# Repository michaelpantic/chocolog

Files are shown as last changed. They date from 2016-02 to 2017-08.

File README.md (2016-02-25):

# chocolog

Folder description:
--------------------

- src: All arduino source files
- libraries: All external libraries to be copied in users library folder
- libraries_root: Libraries that need to be exchanged in /usr/share/arduino/libraries. Just the LCD Library that supports shift registers out of the box.

Used Hardware:
--------------

- Arduno Uno
- Sparkfun micro SD-Shield
- Basic 16x2 Character LCD 5V and Shift Register 74HC595 (connected using SPI)
- DS1307RTC Clock break out (connected using I2C)
- 10x DS18B20 Temperature Sensor (Connected using single pin)

Bill of material:
-----------------
- Real Time Clock Module x1
- Audio Cable TRRS - 18" (pigtail) x3
- Shift Register 8-Bit - 74HC595 x2
- Trimpot 10K with Knob x1
- Resistor Kit - 1/4W (500 total) x1
- Audio Jack - 3.5mm (Panel Mount) x3
- Metal Pushbutton - Momentary (16mm, Red) x1
- Metal Pushbutton - Momentary (16mm, Blue) x1
- microSD Shield x1
- Arduino Uno - R3 x1
- Basic 16x2 Character LCD - White on Black 5V x1
- Hook-up Wire - Black (22 AWG) x1
- Heat Shrink - Black 5' x 1/4" x1
- Arduino Stackable Header - 8 Pin x3
- Arduino Stackable Header - 6 Pin x2
- Screw - Phillips Head (1/2", 4-40, 10 pack) x1
- Nut - Metal (4-40, 10 pack) x1
- DC Barrel Jack - Panel Mount x1
- Standoff - Nylon (4-40; 3/8"; 10 pack) x1
- Enclosure - Aluminum (120x95x35mm) x1
- Temperature Sensor - Waterproof (DS18B20) x10
- Wall Adapter Power Supply - 5V DC 2A (Barrel Jack) x1

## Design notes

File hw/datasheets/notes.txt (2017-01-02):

bq24072 - see ti reference design
 - max Vout 3.7v / min Vout >3.4v
 - Use low dropout regulator for 3.3.v (that also supports up to 5v)
 - Use boost converter for 5V

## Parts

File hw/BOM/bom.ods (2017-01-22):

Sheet: Sheet1
BOM Logger
Supplier | Count | Subsystem | Order N | Description | Currency | Item Cost | Total per Device
Sparkfun
 | 1 | UI | LCD-00709 | Basic 16x2 Character LCD - White on Black 5V | USD | 15.95 | 15.95
 | 1 | UI | PRT-13838 | Enclosure - Aluminum (120x94.5x34mm) | USD | 4.95 | 4.95
 | 10 | SENS | SEN-11050 | Temperature Sensor - Waterproof (DS18B20) | USD | 9.95 | 99.5
 | 1 | PCB | PRT-0078 | Coin cell Holder | USD | 1.5 | 1.5
 | 4 | PWR/SIG | PRT-11475 | Panel Connectors | USD | 2.95 | 11.8
 | 1 | PWR | TOL-12889 | Wall Adapter Power Supply - 5V DC 2A (Barrel Jack) | USD | 5.95 | 5.95
 | 1 | UI | PRT-10877 | 2X3 Shrouded Male Header | USD | 1.5 | 1.5
 | 1 | UI | PRT-10651 | 2X3 Crimp on Female Header | USD | 0.35 | 0.35
 | 1 | UI | PRT-08506 | 2X5 Shrouded Male Header | USD | 1.5 | 1.5
 | 1 | UI | PRT-10650 | 2x5 Crimp on Female Header | USD | 0.5 | 0.5
 | 1 | PCB | COM-09806 | Trimpot | USD | 0.95 | 0.95
 |  |  |  | Breakaway headesr
 |  |  |  | 32.768 khz oscilator | USD | 0.48 | 0
 |  |  |  | FTDI Cable
 | 1 | MC | COM-08720 | Mini Pushbutton Switch – SMD | USD | 0.5 | 0.5
 | 1 | Common | CAB-10647 | Ribbon Cable | USD | 4.95
 | 1 | MC | COM-00536 | Crystal 16 MHZ |  | 0.95
Adafruit
 | 1 | PWR | 1781 | Lithium Ion Cylindrical Battery - 3.7v 2200mAh | USD | 9.95 | 9.95
 | 1 | PWR | 1944 | PowerBoost 500 Charger - Rechargeable 5V Lipo USB Boost @ 500mA+ | USD | 14.95 | 14.95
 | 1 | UI | COM-11967 | Metal Pushbutton - Momentary (16mm, Blue) | USD | 4.95 | 4.95
 | 1 | UI | COM-11966 | Metal Pushbutton - Momentary (16mm, Red) | USD | 4.95 | 4.95
 | 1 | UI | COM-11974 | Metal Pushbutton - Latching (16mm, Yellow) | USD | 4.95 | 4.95
Elecrow
 | 1 | PCB |  | PCB | USD | 10 | 10
Digikey
 | 1 | PCB | 478-4061-1-ND | SD SLOT | USD | 5.4 | 5.4
 | 1 | PCB | ATMEGA328-PU-ND | MC | USD | 3.24 | 3.24
 | 1 | PCB | ED3050-5-ND | DIP28 socket | USD | 0.32 | 0.32
 | 1 | RTC | DS1307Z+-ND | RTC Clock | USD | 3.13 | 3.13
 | 1 | PCB | 296-14529-1-ND | Hex converter | USD | 0.43 | 0.43
 | 1 | PCB | 568-1483-1-ND | Shift register 74LS595D | USD | 0.45 | 0.45
 | 3 | RTC | 399-3677-1-ND | 0.1uf Capacitor | USD | 0.36 | 1.08
 | 3 | RTC | 311-4.70KFRCT-ND | 1206 4.7kOhm | USD | 0.09 | 0.27
 | 1 | PWR | MCP1700T3302ETTCT-ND | LDO regulator | USD | 0.38 | 0.38
 | 4 | PWR | 399-9449-1-ND | 1uf 1206 Capacitor | USD | 0.33 | 1.32
 | 2 | MC | 311-10.0KFRCT-ND | 1206 10kOhm
 | 2 | MC | 399-8165-1-ND | 22pf 1206 Capacitor |  |  | 210.72
 | 1 | UI | 311-8.2ERCT-ND | 1206 6 Ohm

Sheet: Sheet2
Capacity | 2200 | [mAh]
Votlage | 3.7 | [V]
 | 8.14 | [Wh]
Nominal V | 5 | [V]
Average Cur | 25 | [mA]
Efficiency | 0.85
 | 0.10625 | [W/h]
 | 76.6117647059
Orders
Supplier | What | Amount | Curr | Shipped | Received | Billed | Tracking
Elecrow | PCB 10x | 76.61 | USD | X | X
DX | 25x GX16 connector | 42.59 | USD | X |  |  | RC316704439NL
Adafruit | Buttons, Lipo charger, batteries | 168 | USD | X | X
Sparkfun | Loads of stuff | 547 | USD | X | X
Digikey | Loads of other stuff | 67 | EUR | X | X
Sorotec | Fraeser | 28 | EUR | X | X
Adafruit v2 | 5xHumid / 2 metal red/ 2 metal blue/3 onoff white / 3 bat / 3 charger | 228
Sparkfun v2 | 22 x ds18b20, 2 x case, 1x Display, +35 Random | 348.66
Digikey v2 |  | 73
 | Total orderings: | 1578.86
 | Flight | 940
 |  | 2518.86
 |  | 503.772
 |  | 2375
DX-16
 | Gehäuse + Sensoren | 3
 | Durchschleif strom | 1
 | Durchschleif sensor | 1

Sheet: Sheet3
Ordering v2
Digikey
 |  | HM1458-ND | Case | 6
 | PCB | 478-4061-1-ND | SD SLOT | 3
 | PCB | ATMEGA328-PU-ND | MC | 2
 | PCB | ED3050-5-ND | DIP28 socket | 2
 | RTC | DS1307Z+-ND | RTC Clock | 3
 | PCB | 296-14529-1-ND | Hex converter | 3
 | PCB | 568-1483-1-ND | Shift register 74LS595D | 3
 | RTC | 399-3677-1-ND | 0.1uf Capacitor | 10
 | RTC | 311-4.70KFRCT-ND | 1206 4.7kOhm
 | PWR | MCP1700T3302ETTCT-ND | LDO regulator | 3
 | PWR | 399-9449-1-ND | 1uf 1206 Capacitor | 10
 | MC | 311-10.0KFRCT-ND | 1206 10kOhm | 5
 | MC | 399-8165-1-ND | 22pf 1206 Capacitor | 10
 | UI | 311-8.2ERCT-ND | 1206 6 Ohm | 5
 |  | T1348-1-ND | Cable | 5
Adafruit
 | PWR | 1781 | Lithium Ion Cylindrical Battery - 3.7v 2200mAh | 3
 | PWR | 1944 | PowerBoost 500 Charger - Rechargeable 5V Lipo USB Boost @ 500mA+ | 3
 | UI | COM-11967 | Metal Pushbutton - Momentary (16mm, Blue) | 2
 | UI | COM-11966 | Metal Pushbutton - Momentary (16mm, Red) | 2
 | UI | COM-11974 | Metal Pushbutton - Latching (16mm, Yellow) | 3
 |  |  | SHT31 | 5
Sparkfun
 | UI | LCD-00709 | Basic 16x2 Character LCD - White on Black 5V | 2
 | UI | PRT-13838 | Enclosure - Aluminum (120x94.5x34mm) | 2
 | SENS | SEN-11050 | Temperature Sensor - Waterproof (DS18B20) | 22
 | PCB | PRT-0078 | Coin cell Holder | 3
 | PWR | TOL-12889 | Wall Adapter Power Supply - 5V DC 2A (Barrel Jack) | 3
 | UI | PRT-10877 | 2X3 Shrouded Male Header | 2
 | UI | PRT-10651 | 2X3 Crimp on Female Header | 2
 | UI | PRT-08506 | 2X5 Shrouded Male Header | 2
 | UI | PRT-10650 | 2x5 Crimp on Female Header | 2
 | PCB | COM-09806 | Trimpot | 2
 |  |  | Breakaway headesr | X
 |  |  | 32.768 khz oscilator | 3
 |  |  | FTDI Cable | 1
 | MC | COM-08720 | Mini Pushbutton Switch – SMD | 3
 | MC | COM-00536 | Crystal 16 MHZ | 3
 |  |  | Stecker | 5

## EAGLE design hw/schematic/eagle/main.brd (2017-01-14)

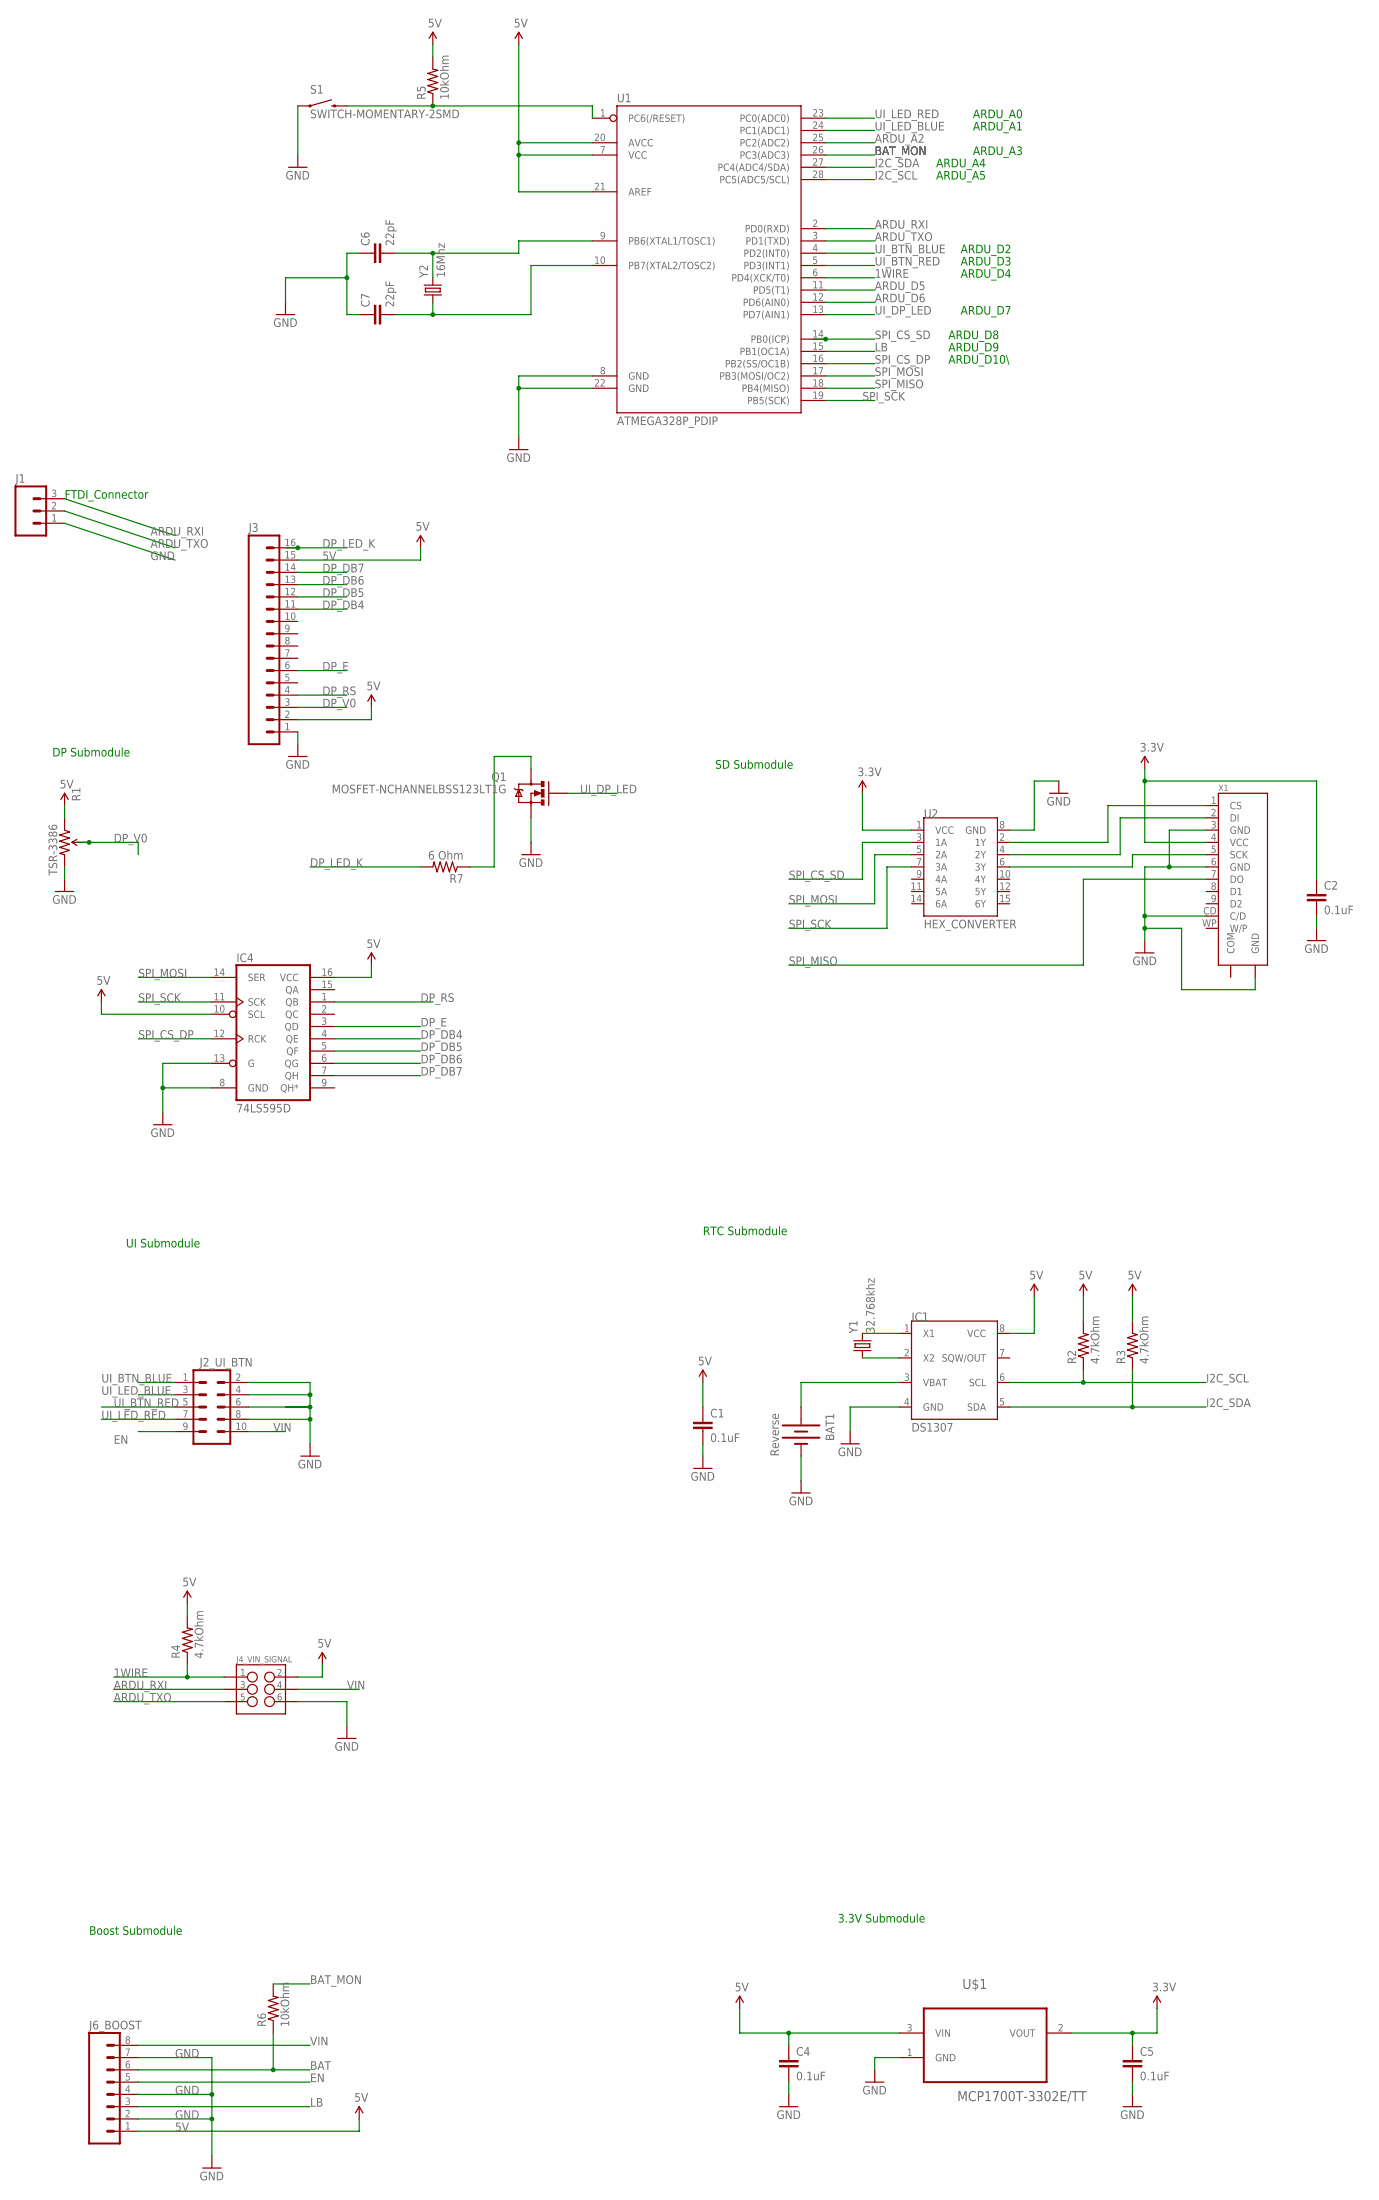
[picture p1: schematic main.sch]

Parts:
BAT1: Reverse; BATTCOM_20MM_PTH
C1, C2, C4, C5: 0.1uF; 1206
C6, C7: 22pF; 1206
IC1: DS1307; SOIC-8
IC4: 74LS595D; SO16
J1: M03LOCK; 1X03_LOCK
J2_UI_BTN: M05X2SHD; 2X5-SHROUDED
J3: M16PTH; 1X16
J4_VIN_SIGNAL: M03X2SHROUD; 2X3-SHROUDED
J6_BOOST: M08; 1X08_ROUND
Q1: MOSFET-NCHANNELBSS123LT1G; SOT23-3
R1: TSR-3386; 3386U
R2, R3, R4: 4.7kOhm; 1206
R5, R6: 10kOhm; 1206
R7: 6 Ohm; 1206
S1: SWITCH-MOMENTARY-2SMD; TACTILE-SWITCH-SMD
U1: ATMEGA328P_PDIP; DIL28-3
U2: HEX_CONVERTER; SO016
U$1: MCP1700T-3302E/TT; SOT95P237X112-3N
X1: SD-SOCKET-AVX
Y1: 32.768khz; CRYSTAL-32KHZ-SMD-MELF
Y2: 16Mhz; HC49US

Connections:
1WIRE: J4_VIN_SIGNAL.1, R4.1, U1.6 (PD4(XCK/T0))
3.3V: C2.1, C5.1, U2.1 (VCC), U$1.2 (VOUT), X1.4 (VCC)
5V: C1.1, C4.1, IC1.8 (VCC), IC4.10 (SCL), IC4.16 (VCC), J3.2, J3.15, J4_VIN_SIGNAL.2, J6_BOOST.1, R1.1 (CCW), R2.2, R3.2, R4.2, R5.2, U1.7 (VCC), U1.20 (AVCC), U1.21 (AREF), U$1.3 (VIN)
ARDU_A2: U1.25 (PC2(ADC2))
ARDU_D5: U1.11 (PD5(T1))
ARDU_D6: U1.12 (PD6(AIN0))
ARDU_RXI: J1.3, J4_VIN_SIGNAL.3, U1.2 (PD0(RXD))
ARDU_TXO: J1.2, J4_VIN_SIGNAL.5, U1.3 (PD1(TXD))
BAT: J6_BOOST.6, R6.1
BAT_MON: R6.2, U1.26 (PC3(ADC3))
DP_DB4: IC4.4 (QE), J3.11
DP_DB5: IC4.5 (QF), J3.12
DP_DB6: IC4.6 (QG), J3.13
DP_DB7: IC4.7 (QH), J3.14
DP_E: IC4.3 (QD), J3.6
DP_LED_K: J3.16, R7.2
DP_RS: IC4.1 (QB), J3.4
DP_V0: J3.3, R1.2 (WIPER)
EN: J2_UI_BTN.9, J6_BOOST.5
GND: BAT1.2 (-), C1.2, C2.2, C4.2, C5.2, C6.1, C7.1, IC1.4 (GND), IC4.8 (GND), IC4.13 (G), J1.1, J2_UI_BTN.2, J2_UI_BTN.4, J2_UI_BTN.6, J2_UI_BTN.8, J3.1, J4_VIN_SIGNAL.6, J6_BOOST.2, J6_BOOST.4, J6_BOOST.7, Q1.2 (S), R1.3 (CW), S1.1, U1.8 (GND), U1.22 (GND), U2.8 (GND), U$1.1 (GND), X1.3 (GND), X1.6 (GND), X1.CD (C/D), X1.GND@2 (GND)
I2C_SCL: IC1.6 (SCL), R2.1, U1.28 (PC5(ADC5/SCL))
I2C_SDA: IC1.5 (SDA), R3.1, U1.27 (PC4(ADC4/SDA))
LB: J6_BOOST.3, U1.15 (PB1(OC1A))
unnamed: BAT1.1 (+), IC1.3 (VBAT)
unnamed: IC1.2 (X2), Y1.X1 (1)
unnamed: IC1.1 (X1), Y1.X2 (2)
unnamed: U2.2 (1Y), X1.1 (CS)
unnamed: U2.4 (2Y), X1.2 (DI)
unnamed: U2.6 (3Y), X1.5 (SCK)
unnamed: R5.1, S1.3 (2), U1.1 (PC6(/RESET))
unnamed: Q1.3 (D), R7.1
unnamed: C6.2, U1.9 (PB6(XTAL1/TOSC1)), Y2.2
unnamed: C7.2, U1.10 (PB7(XTAL2/TOSC2)), Y2.1
SPI_CS_DP: IC4.12 (RCK), U1.16 (PB2(SS/OC1B))
SPI_CS_SD: U1.14 (PB0(ICP)), U2.3 (1A)
SPI_MISO: U1.18 (PB4(MISO)), X1.7 (DO)
SPI_MOSI: IC4.14 (SER), U1.17 (PB3(MOSI/OC2)), U2.5 (2A)
SPI_SCK: IC4.11 (SCK), U1.19 (PB5(SCK)), U2.7 (3A)
UI_BTN_BLUE: J2_UI_BTN.1, U1.4 (PD2(INT0))
UI_BTN_RED: J2_UI_BTN.5, U1.5 (PD3(INT1))
UI_DP_LED: Q1.1 (G), U1.13 (PD7(AIN1))
UI_LED_BLUE: J2_UI_BTN.3, U1.24 (PC1(ADC1))
UI_LED_RED: J2_UI_BTN.7, U1.23 (PC0(ADC0))
VIN: J2_UI_BTN.10, J4_VIN_SIGNAL.4, J6_BOOST.8

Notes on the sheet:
RTC Submodule
SD Submodule
DP Submodule
UI Submodule
Boost Submodule
3.3V Submodule
ARDU_A4
ARDU_A5
ARDU_D10\
ARDU_D8
ARDU_A0
ARDU_A1
ARDU_D4
ARDU_D3
ARDU_D2
ARDU_A3
ARDU_D9
ARDU_D7
FTDI_Connector

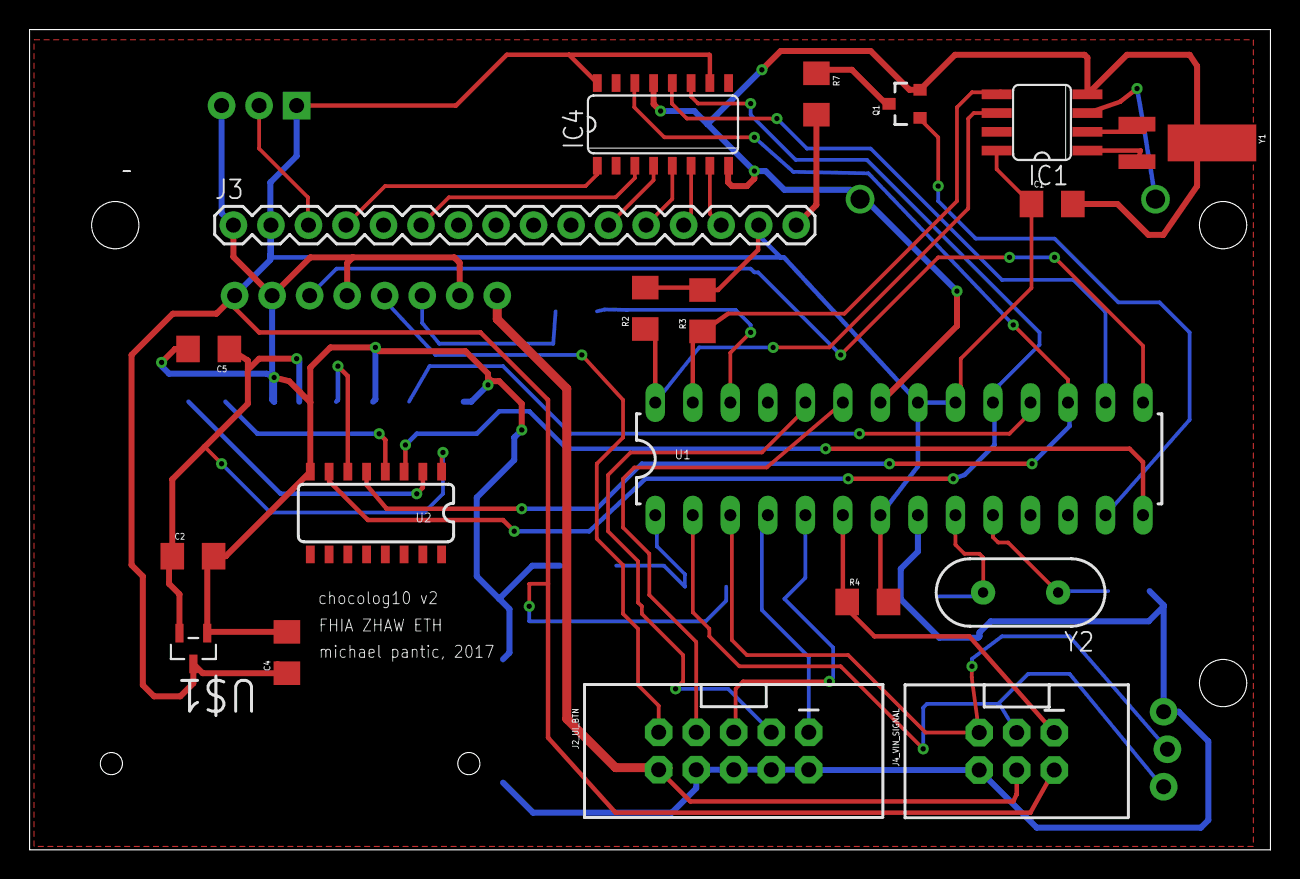
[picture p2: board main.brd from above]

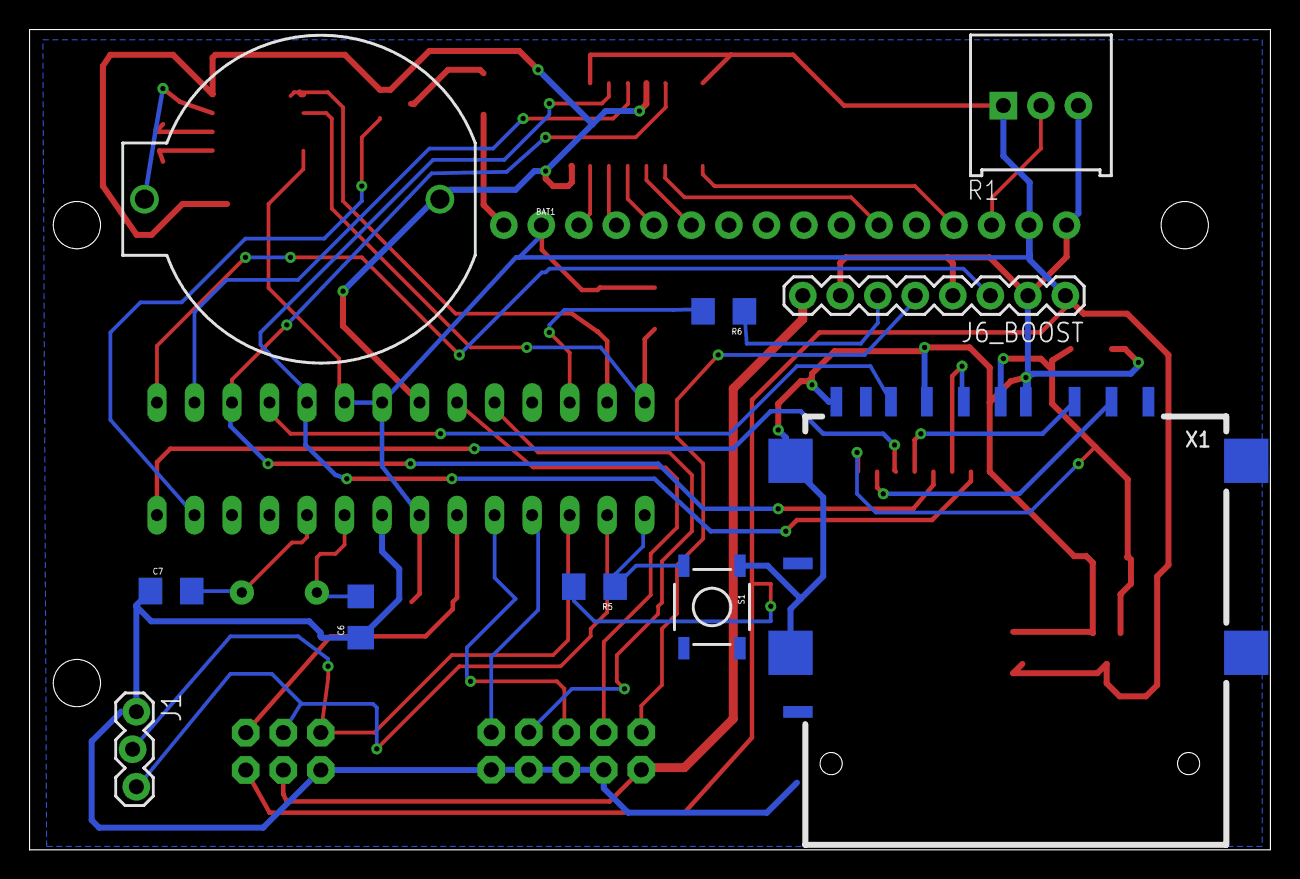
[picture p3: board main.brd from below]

Board: 2 copper layers, 84.0 x 55.5 mm, 29 parts (10 on the bottom side), 41 nets.

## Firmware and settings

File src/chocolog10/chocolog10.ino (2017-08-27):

#define SDA_PORT PORTD
#define SDA_PIN 0
#define SCL_PORT PORTD
#define SCL_PIN 1
#define I2C_TIMEOUT 100
#define I2C_FASTMODE 1

#include <SoftWire.h>
#define SHT31_DEFAULT_ADDR    0x44
#define SHT31_MEAS_HIGHREP_STRETCH 0x2C06
#define SHT31_MEAS_MEDREP_STRETCH  0x2C0D
#define SHT31_MEAS_LOWREP_STRETCH  0x2C10
#define SHT31_MEAS_HIGHREP         0x2400
#define SHT31_MEAS_MEDREP          0x240B
#define SHT31_MEAS_LOWREP          0x2416
#define SHT31_READSTATUS           0xF32D
#define SHT31_CLEARSTATUS          0x3041
#define SHT31_SOFTRESET            0x30A2
#define SHT31_HEATEREN             0x306D
#define SHT31_HEATERDIS            0x3066

#include <Time.h>
#include<SdFat.h>
#include <avr/pgmspace.h>
#include <EEPROM.h>
#include "LowPower.h"

/*********************************************************************/
/*                       Definitions                                 */
/*********************************************************************/



#define DATE_DELIMITER '-'
#define TIME_DELIMITER ':'
#define UI_FLASH 501
#define UI_BLINK  500
#define UI_ON  1
#define UI_OFF  0


//UI definitions
#define PAGE_SIZE 33 //with termination char
#define CLOCK_PAGE 0
#define DATA_PAGE 1
#define RECORDING_PAGE 2
#define SENSOR_PAGE 3
#define TRANSMIT_PAGE 4
#define DIAG_PAGE 5


//Error codes
#define CLOCK_ERROR 1
#define CLOCK_STOPPED 2
#define SD_NOCARD 1

#define POWER_MODE_NORMAL 0
#define POWER_MODE_SAVE 1
#define POWER_MODE_SHUTDOWN 254

typedef unsigned char PROGMEM   prog_uchar;
typedef uint16_t PROGMEM   prog_uint16_t;

void startup_error(const __FlashStringHelper* message)
{
  
   char* pageBuffer = pub_getEmptyPage(0);  
   strcpy_P(pageBuffer, (const char*)message);

 
   Serial.print(message);

   ui_outputLoop();
   while(1){}
}

void shutdown_lowbat()
{
     // todo
       
}

void power_save()
{
  // sleep for a second
  LowPower.powerDown(SLEEP_1S, ADC_OFF, BOD_OFF);  
  extern volatile unsigned long timer0_millis;
  noInterrupts();
  timer0_millis += 1000;
  interrupts();
}

void setup()
{ 

  pinMode(8, OUTPUT); 
  pinMode(10, OUTPUT);    


//  Serial.begin(115200);
  delay(500);
  pwrmgmt_initialize();
  ui_initialize();
  data_initialize();
  clock_initialize();
  humid_init();
  
  storage_initialize();
  sensor_initialize();
 
  ui_hw_test();
  switch(clock_test())
  {
    case 0: break; //everything ok
    
    case CLOCK_ERROR: startup_error(F("CLOCK ERROR"));
                      break;
                      
    case CLOCK_STOPPED: 
                        if(!clock_settime())
                        {
                          startup_error(F("CLOCK NOT SET"));
                        }
                        break;
  
  }
 
  
  switch(storage_test())
  {
    case 0: break;
    
    case SD_NOCARD: startup_error(F("NO SD CARD"));
                    break;
  
  }
  
  sensor_test();

}



void loop()
{
  

  //process any inputs by the buttons
  ui_inputLoop();
  
  //update current Time
  clock_loop();
 
  //read/scan sensors
  sensor_loop();
   
  //update storage and serial
  storage_loop();
  
  humid_loop();
  
  //update data display page
  data_loop();
  
  //update diag display page
  pwrmgmt_loop();
  
  //update LCD / Buttons
  ui_outputLoop(); 
  


  if(pwrmgmt_save_power())
  {
    power_save();
  }
}

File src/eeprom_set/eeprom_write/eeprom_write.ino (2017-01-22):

/*
 * EEPROM Write
 *
 * Stores values read from analog input 0 into the EEPROM.
 * These values will stay in the EEPROM when the board is
 * turned off and may be retrieved later by another sketch.
 */

#include <EEPROM.h>

/** the current address in the EEPROM (i.e. which byte we're going to write to next) **/
int addr = 1023;
int serialNumber = 7;
void setup() {
  Serial.begin(9600);
   Serial.println("Type w to start");
  char bla = Serial.read();
  while(bla!='w')
  {
    bla = Serial.read();
    }
   
   int oldval = EEPROM.read(addr);


  EEPROM.write(addr, serialNumber);
  Serial.print("Written serial num ");
  Serial.print(serialNumber);
  Serial.print(" into address ");
  Serial.println(addr);

  int val = EEPROM.read(addr);

  Serial.print("Old value = ");
  Serial.print(oldval);
  Serial.print(" / New value = ");
  Serial.println(val);

  Serial.println("Program ended.");
    
}

void loop() {
/*
  Serial.println("Type w to start");
  char bla = Serial.read();
  if(bla!='w'){
    return;}
  /*
 
  */
}

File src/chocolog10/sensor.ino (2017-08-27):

/*  Module that
 *   a) scans for available sensors 
 *   b) reads those sensors
 *   c) converts read data into float temperatures
 *
 *  Important: Because Bus operations (read, scan etc) take "a lot" of time, all operations
 *             are carried out piece by piece. For example:
 *             Bus scan: each call of the loop() function, search exactly for 1 new sensor, until all are found
 *             then, each call of the loop() reads exactly 1 sensor, until all are read
 *            
 *             This is done in order to keep the run time of the loop function as small as possible 
 */


#include <OneWire.h>

// Sensor Constants
#define SENSOR_BUS_PIN 4          //1 Wire Bus Pin
#define SENSOR_CONVERT_TIME 1000  // Time a sensor needs to digitalize temperature (750ms according to datasheet..better use 1000ms)
#define SENSOR_READ_INTERVAL 10000  // How often sensors are re-read
#define SENSOR_CMD_CONVERT 0x44   // Command to start temperature digitalization
#define SENSOR_CMD_READ    0xBE   // Command to read sensor memory with temperature

//module states
#define SENSOR_MODULE_DATAINVALID   0  //= No (valid) data present! Start Busscan!
#define SENSOR_MODULE_BUSSCAN 1        //= Busscan in progress
#define SENSOR_MODULE_BUSCONVERT 2     //= Busscan finished, start temperature digitalization!
#define SENSOR_MODULE_BUSWAIT 3        //= Wait for SENSOR_CONVERT_TIME to elapse
#define SENSOR_MODULE_BUSREAD 4        //= Reading Sensors in progress
#define SENSOR_MODULE_DATAVALID 5      //= All sensors read, everything valid! (number and address of sensors, sensor data!



//Display page texts
                              //0         1     ¦¦  2         3
                              //01234567890123456789012345678901
const prog_uchar sensor_pageDefaultText[] PROGMEM = "Sensor Info:           x DS18B20";

//module variables
byte sensor_moduleState = 0;       //current module state (see module states)
byte sensor_scanNum = 0;           //stores how many sensors have alread been found when in BUSSCAN mode
unsigned long sensor_startConversationTime;//stores timestamp of when convesation started(while in BUSWAIT mode)
byte sensor_nextSensorToRead=0;    //sets which sensor will be read enxt when in BUSREAD mode
unsigned long sensor_lastValidData;//stores timestamp of last time all sensors had valid data (needed in DATAVALID mode)


byte sensor_subPageNum = 0;  

OneWire sensor_bus(SENSOR_BUS_PIN);


void sensor_initialize()
{
  //nothing to initalize
}

/* Performs busscan for testing purposes and returns number of sensors found
 */
int sensor_test()
{
  //read all sensors address and return number of found sensors
   while(sensor_scanBus()); //search until all found
 
   return pub_sensor_count;
}

/*  Periodically read sensors and update page
 */
void sensor_loop()
{

  switch(sensor_moduleState)
  {
      case SENSOR_MODULE_DATAINVALID:
        // no valid data. Reset module variables
        // and set mode to BUSSCAN
        pub_sensor_data_valid = 0;
        sensor_scanNum = 0;
        pub_sensor_changed = 0;
        sensor_moduleState = SENSOR_MODULE_BUSSCAN;
        break;
        
      case SENSOR_MODULE_BUSSCAN:
        // Busscan in progress. while in this state,
        // each loop execution detects maximal one next sensor
        // if no new sensors have been detected (scanBus returns false), 
        // the scan is finished and next state is BUSCONVERT
        if(!sensor_scanBus())
        {
         sensor_moduleState = SENSOR_MODULE_BUSCONVERT; 
        }
        break;
        
      case SENSOR_MODULE_BUSCONVERT:
        //After Busscan, we know which sensors are present
        //Send them the convert command (= all sensors should read temperature and digitalize)
        //then set state to BUSWAIT
        sensor_busSendConvertCommand(); //send command
        sensor_nextSensorToRead=0;      //start reading with sensor 0
        sensor_startConversationTime = millis(); //conversation started!
          
        sensor_moduleState = SENSOR_MODULE_BUSWAIT;
        break;
        
      case SENSOR_MODULE_BUSWAIT:
        //Convert command has been sent. In this state
        //we only wait for the dataReadyTime to elapse.
        //if so, set state to BUSREAD        
        if(pub_intervalElapsed(sensor_startConversationTime, SENSOR_CONVERT_TIME))
        {
          sensor_moduleState = SENSOR_MODULE_BUSREAD;
        }
        break;
        
      case SENSOR_MODULE_BUSREAD:
          //Sensors are ready to be read.
          //read 1 sensor every loop() execution until
          //sensor_count has been reached
          if(sensor_nextSensorToRead<pub_sensor_count)
          {
           sensor_busReadSensorData(sensor_nextSensorToRead);
           sensor_nextSensorToRead++;
          }
          else //if all sensors have been read,
               //set data_valid = 1 and module state to DATAVALID 
          {
             sensor_moduleState = SENSOR_MODULE_DATAVALID;
             sensor_lastValidData = millis();
             pub_sensor_data_valid = 1;
          } 
      break;
      
      case SENSOR_MODULE_DATAVALID:
        //Data is valid. If READ_INTERVAL has been elapsed, start
        // again with DATAINVALID mode
        
        pub_sensor_changed = 0; //reset changed flag
        
        if(pub_intervalElapsed(sensor_lastValidData, SENSOR_READ_INTERVAL))
        {
          sensor_moduleState = SENSOR_MODULE_DATAINVALID;
        }
        break;
        
      default:
        sensor_moduleState = SENSOR_MODULE_DATAINVALID;
        break;        
    
  }


  //and in any state update display page
  sensor_updatePages();
  
}
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

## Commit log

2016-02-25 Working version of 2014
    [LCD_using_74HC595_and_SPI.fz]
2016-02-25 Fixed folder name for arduino IDE
    [apublic.ino, chocolog10.ino, clock.ino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]
2017-01-02 Eagles files
    [bom.ods, main.brd, main.sch]
2017-01-14 Schematic, Gerbers used in production
    [bom.ods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]
2017-01-14 First buggy implementation of energy save mode
    [apublic.ino, chocolog10.ino, clock.ino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]
2017-01-22 3df files
    [bom.ods]
2017-02-26 Base code for humdity sensor
2017-08-27 Working humidity sensor

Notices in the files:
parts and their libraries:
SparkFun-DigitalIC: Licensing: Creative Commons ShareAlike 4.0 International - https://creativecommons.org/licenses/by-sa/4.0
